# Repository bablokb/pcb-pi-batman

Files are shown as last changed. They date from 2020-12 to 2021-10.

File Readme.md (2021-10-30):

A pcb to support the battery management of mobile Pi-projects
=============================================================

Overview
--------

Since the Pi still drains power after shutdown, it is necessary
for battery-based projects to turn of the supply. This project uses
a very simple design to implement this.

One requisite is a DCDC-converter with an enable pin. As an alternative,
you can use a mosfet to switch power.

This repository contains two pcbs: the so called
_"minimal pcb"_ is nothing more than a flip-flop (SN74HC(T)74) with some
connectors for the converter and the Pi. The second pcb is a pHat designed
for a Pi-Zero.

Schematic Min-PCB
-----------------

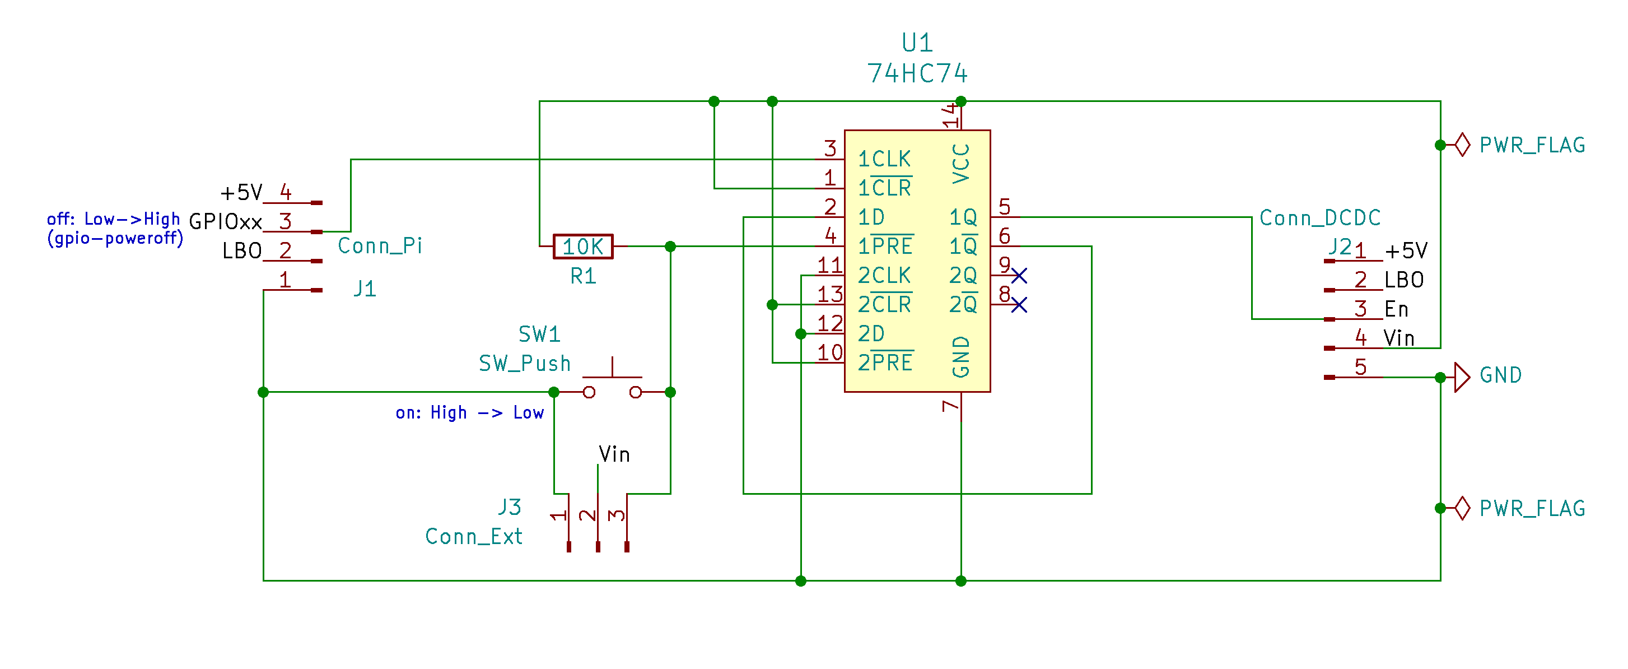
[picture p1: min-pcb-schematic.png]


The flip-flop drives the enable pin of the converter (pin 1Q). A button
(and/or RTC or sensor) pulls the reset pin (/1PRE) low to turn on power. A
GPIO from the Pi is connected to the clock-pin (pin 1CLK). The Pi will
pull this pin high on shutdown (see below). This will change the state
of the flip-flop: 1Q will take the value of 1D, which in turn is
connected to the inverted value /1Q (i.e. 1Q will switch to the current
value of /1Q).

The additional pin labelled _"LBO"_ is optional. Converters with a battery
monitoring can output a signal (_"low battery out"_) and if this is
connected to the Pi a program can react e.g. with an emergency
shutdown or an alarm if LBO is set.

Min-Pcb
-------

This is a very small pcb, useful if your project design needs it near
the battery pack:

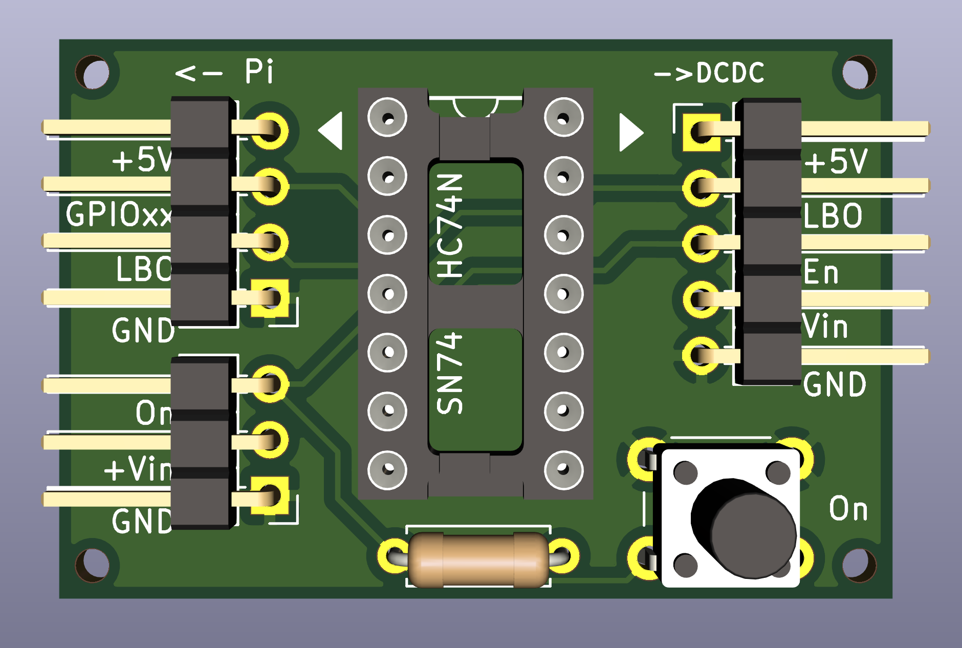
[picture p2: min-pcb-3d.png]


The layout is simple and the complete kicad-project is available in the
directory `min-pcb`.

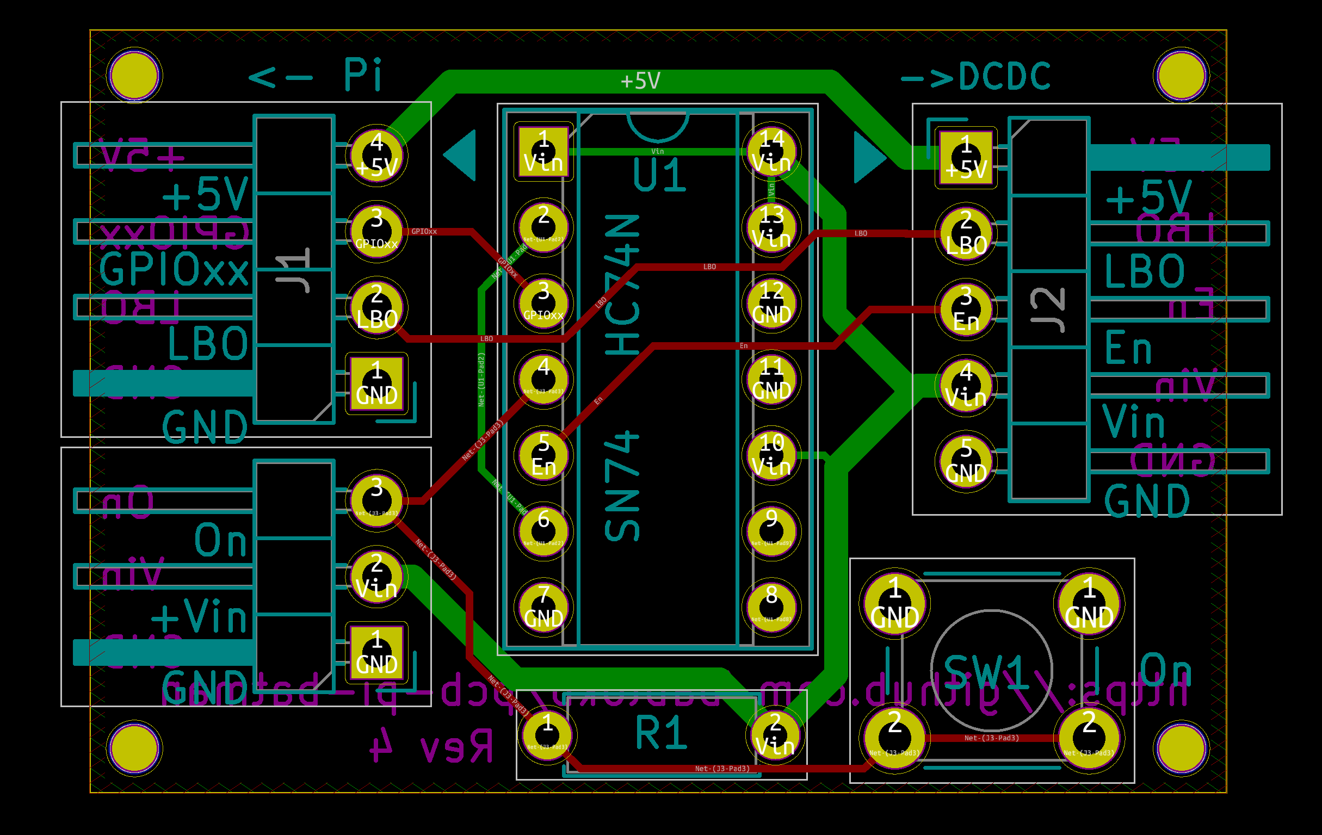
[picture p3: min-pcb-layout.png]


Schematic pHat-Pcb
------------------

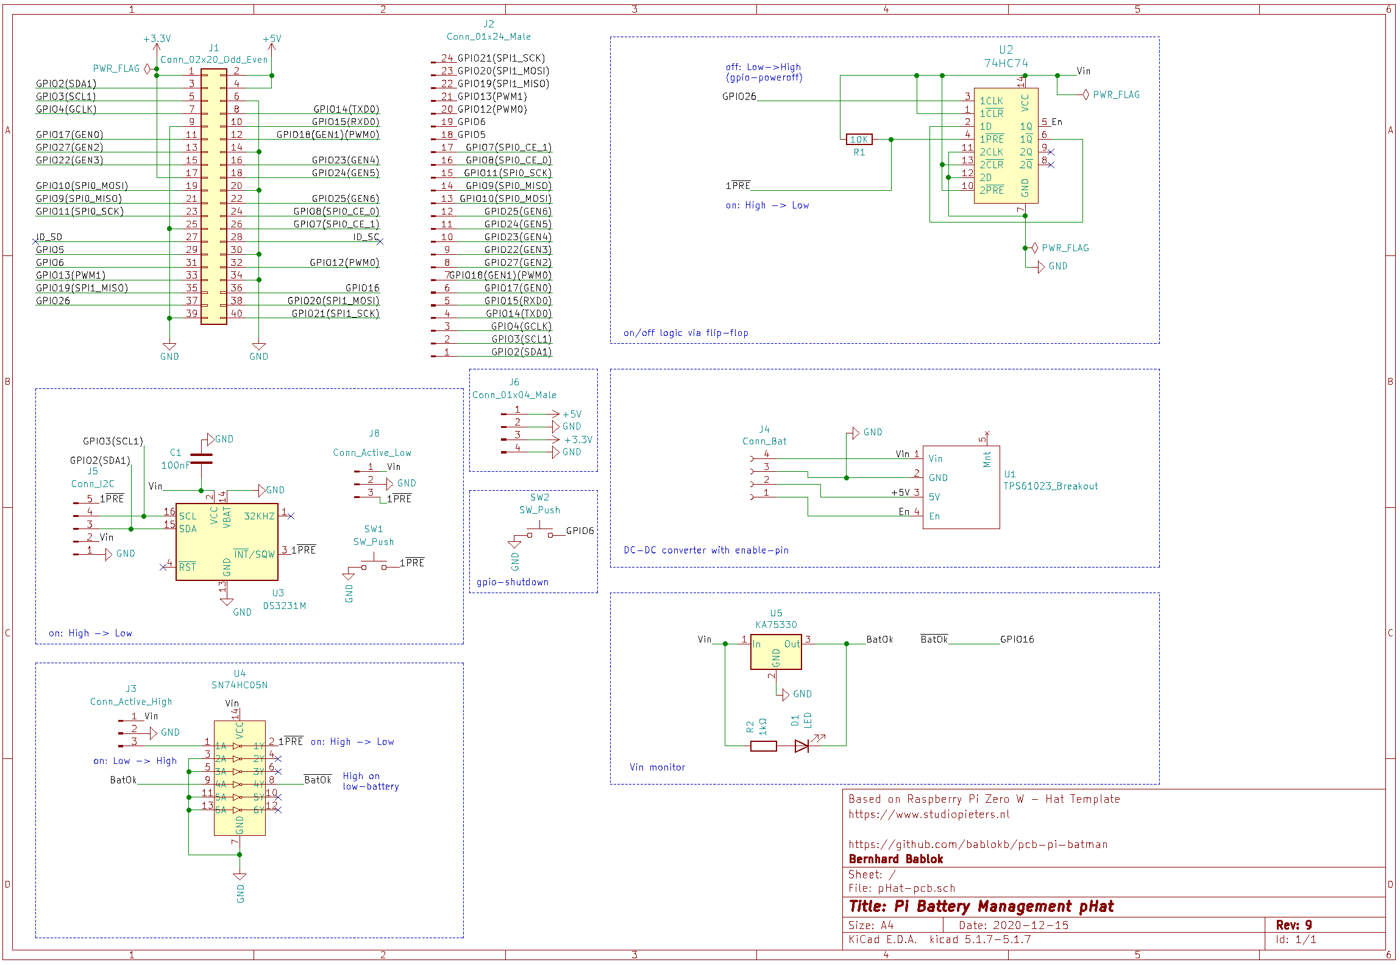
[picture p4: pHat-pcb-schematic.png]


This circuit is more sophisticated. The basis is the same, but it adds an
RTC (DS3231) for time-based boots and an inverter, mainly for turning on
power with a low-high transition. Also, the pcb has space for a
TPS61023 breakout (DC-DC converter) and for a KA75330 voltage-supervisor IC.

If you populate a LED+resistor, it will light up once the input
voltage drops below something like 3.15-3.45V (range of KA75330 according
to the datasheet). But in fact it might be a better idea not to
populate these two components: if voltage is low you don't want to
waste the rest of the battery for lighting up a LED?! For this reason
the inverted signal is also connected to GPIO16, so the Pi can react
and maybe shutdown or send a low-battery mail.

Another optional component is a second switch, directly attached to the Pi
(GPIO6). See the configuration section below to see how you can
shutdown the Pi with this button (you can use it for other purposes as well).

pHat-Pcb
--------

The format of the pcb is a zero-sized hat without beeing a formal pHat:

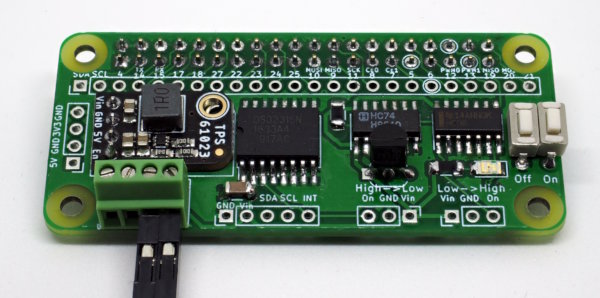
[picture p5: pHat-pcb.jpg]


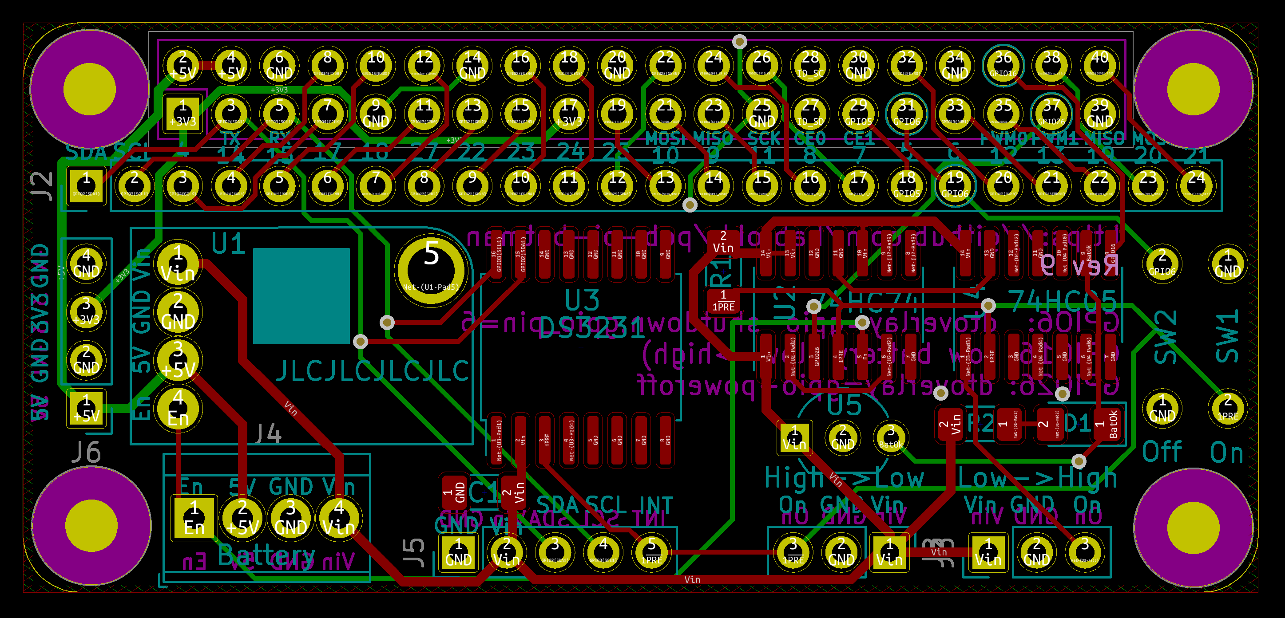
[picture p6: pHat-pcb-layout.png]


The hat breaks out most of the GPIOs, except for GPIO6, GPIO16 and GPIO26.

The following components are optional:

  - TPS61023 DC-DC converter
    (you can externaly connect battery, 5V and enable pin instead)
  - DS3131 RTC
  - KA75330 + LED + resistor
  - all connectors

Pi Configuration Min-Pcb
------------------------

The Pi has to signal shutdown to the pcb. Simply add the following
line to your `/boot/config.txt`:

    dtoverlay=gpio-poweroff,gpiopin=26

Note that the default is GPIO26 (physical pin 37). You cannot
just use any pin, since on power-on the pin has to be pulled low
until the gpio-poweroff driver takes over.

Pi Configuration pHat-Pcb
-------------------------

This pcb has multiple connections to the Pi. Add following lines to
your `/boot/config.txt`:

    dtoverlay=i2c-rtc,ds3231,wakup-source
    dtoverlay=gpio-shutdown,gpio_pin=6
    dtoverlay=gpio-poweroff,gpiopin=26
    dtoverlay=gpio-key,gpio=16,active_low=0,gpio_pull=off,label=lbo,keycode=xx

The first line is to activate the rtc, the last line triggers the
configured key on a battery low signal. This is just an example, there
are other ways to monitor GPIO16 for a low-high transition.

For the rtc you need an additional file `/etc/udev/rules.d/85-hwclock.rules`
with the content:

    KERNEL=="rtc0", RUN+="/sbin/hwclock -s -u -f $root/$name"

License
-------

Shield: [![CC BY-SA 4.0][cc-by-sa-shield]][cc-by-sa]

This work is licensed under a
[Creative Commons Attribution-ShareAlike 4.0 International
License][cc-by-sa].

[][cc-by-sa]

[cc-by-sa]: http://creativecommons.org/licenses/by-sa/4.0/
[cc-by-sa-image]: https://licensebuttons.net/l/by-sa/4.0/88x31.png
[cc-by-sa-shield]:
https://img.shields.io/badge/License-CC%20BY--SA%204.0-lightgrey.svg

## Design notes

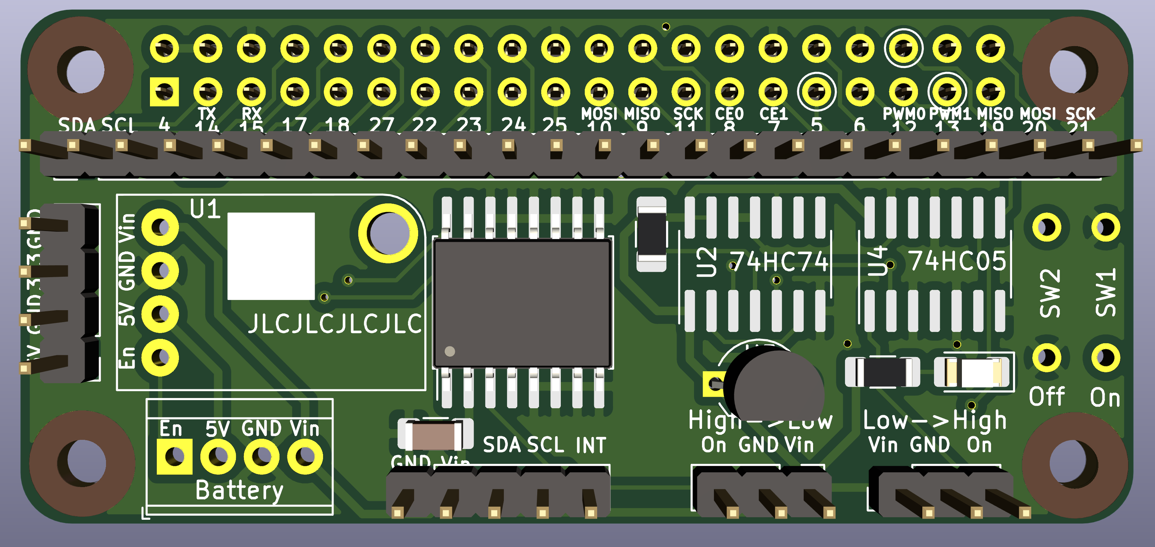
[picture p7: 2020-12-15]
pHat-pcb-3d.png

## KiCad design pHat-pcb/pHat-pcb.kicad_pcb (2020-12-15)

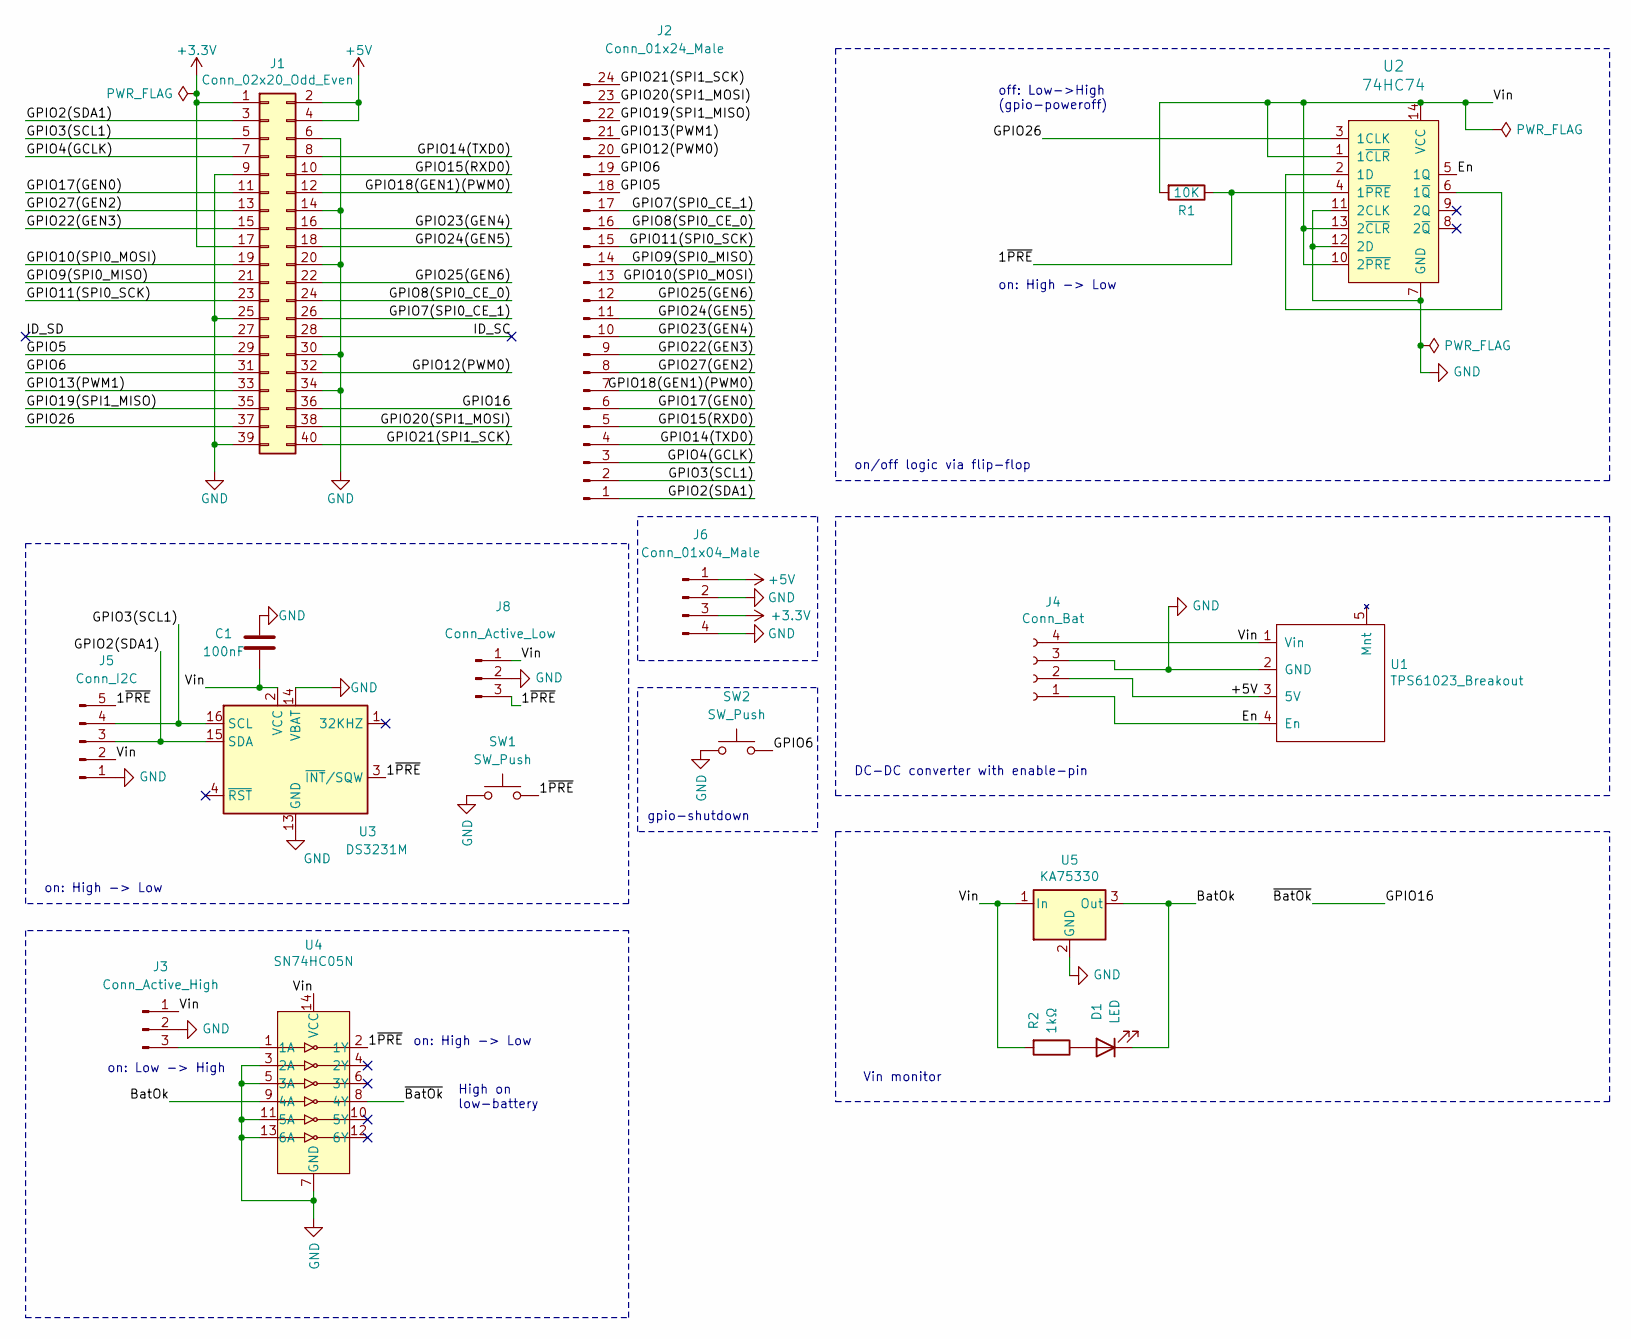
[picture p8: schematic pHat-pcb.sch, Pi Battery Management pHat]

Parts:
C1: 100nF; C_1206_3216Metric_Pad1.33x1.80mm_HandSolder
D1: LED; LED_1206_3216Metric_Pad1.42x1.75mm_HandSolder
J1: Conn_02x20_Odd_Even; PinSocket_2x20_P2.54mm_Vertical
J2: Conn_01x24_Male; PinHeader_1x24_P2.54mm_Vertical
J3: Conn_Active_High; PinHeader_1x03_P2.54mm_Vertical
J4: Conn_Bat; TerminalBlock_TE_282834-4_1x04_P2.54mm_Horizontal
J5: Conn_I2C; PinHeader_1x05_P2.54mm_Vertical
J6: Conn_01x04_Male; PinHeader_1x04_P2.54mm_Vertical
J8: Conn_Active_Low; PinHeader_1x03_P2.54mm_Vertical
R1: 10K; R_1206_3216Metric_Pad1.30x1.75mm_HandSolder
R2: 1kΩ; R_1206_3216Metric_Pad1.30x1.75mm_HandSolder
SW1, SW2: SW_Push; SW_PUSH_SLIM_1x4
U1: TPS61023_Breakout
U2: 74HC74; SO-14_3.9x8.65mm_P1.27mm_HandSolder; MPN SN74HC74N; Digi-Key_PN 296-1602-5-ND
U3: DS3231M; SOIC-16W_7.5x10.3mm_P1.27mm_HandSolder
U4: SN74HC05N; SO-14_3.9x8.65mm_P1.27mm_HandSolder
U5: KA75330; TO-92_Inline_Wide

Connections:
+3V3: J1.1, J1.17, J6.3
+5V: J1.2, J1.4, J4.2, J6.1, U1.3 (5V)
/1~PRE: J5.5, J8.3, R1.1, SW1.2, U2.4 (1~PRE), U3.3 (~INT~/SQW), U4.2 (1Y)
/BatOk: D1.1 (K), U4.9 (4A), U5.3 (Out)
/En: J4.1, U1.4 (En), U2.5 (1Q)
/GPIO2(SDA1): J1.3, J2.1, J5.3, U3.15 (SDA)
/GPIO3(SCL1): J1.5, J2.2, J5.4, U3.16 (SCL)
/GPIO4(GCLK): J1.7, J2.3
/GPIO5: J1.29, J2.18
/GPIO6: J1.31, J2.19, SW2.2
/GPIO7(SPI0_CE_1): J1.26, J2.17
/GPIO8(SPI0_CE_0): J1.24, J2.16
/GPIO9(SPI0_MISO): J1.21, J2.14
/GPIO10(SPI0_MOSI): J1.19, J2.13
/GPIO11(SPI0_SCK): J1.23, J2.15
/GPIO12(PWM0): J1.32, J2.20
/GPIO13(PWM1): J1.33, J2.21
/GPIO14(TXD0): J1.8, J2.4
/GPIO15(RXD0): J1.10, J2.5
/GPIO16: J1.36, U4.8 (4Y)
/GPIO17(GEN0): J1.11, J2.6
/GPIO18(GEN1)(PWM0): J1.12, J2.7
/GPIO19(SPI1_MISO): J1.35, J2.22
/GPIO20(SPI1_MOSI): J1.38, J2.23
/GPIO21(SPI1_SCK): J1.40, J2.24
/GPIO22(GEN3): J1.15, J2.9
/GPIO23(GEN4): J1.16, J2.10
/GPIO24(GEN5): J1.18, J2.11
/GPIO25(GEN6): J1.22, J2.12
/GPIO26: J1.37, U2.3 (1CLK)
/GPIO27(GEN2): J1.13, J2.8
/ID_SC: J1.28
/ID_SD: J1.27
/Vin: C1.2, J3.1, J4.4, J5.2, J8.1, R1.2, R2.2, U1.1 (Vin), U2.1 (1~CLR), U2.10 (2~PRE), U2.13 (2~CLR), U2.14 (VCC), U3.2 (VCC), U4.14 (VCC), U5.1 (In)
GND: C1.1, J1.6, J1.9, J1.14, J1.20, J1.25, J1.30, J1.34, J1.39, J3.2, J4.3, J5.1, J6.2, J6.4, J8.2, SW1.1, SW2.1, U1.2 (GND), U2.7 (GND), U2.11 (2CLK), U2.12 (2D), U3.5 (GND), U3.6 (GND), U3.7 (GND), U3.8 (GND), U3.9 (GND), U3.10 (GND), U3.11 (GND), U3.12 (GND), U3.13 (GND), U3.14 (VBAT), U4.3 (2A), U4.5 (3A), U4.7 (GND), U4.11 (5A), U4.13 (6A), U5.2 (GND)
unnamed: D1.2 (A), R2.1
unnamed: J3.3, U4.1 (1A)
unnamed: U2.2 (1D), U2.6 (1~Q)

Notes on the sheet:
off: Low->High (gpio-poweroff)
on: High -> Low
on: Low -> High
on/off logic via flip-flop
DC-DC converter with enable-pin
High on low-battery
Vin monitor
gpio-shutdown

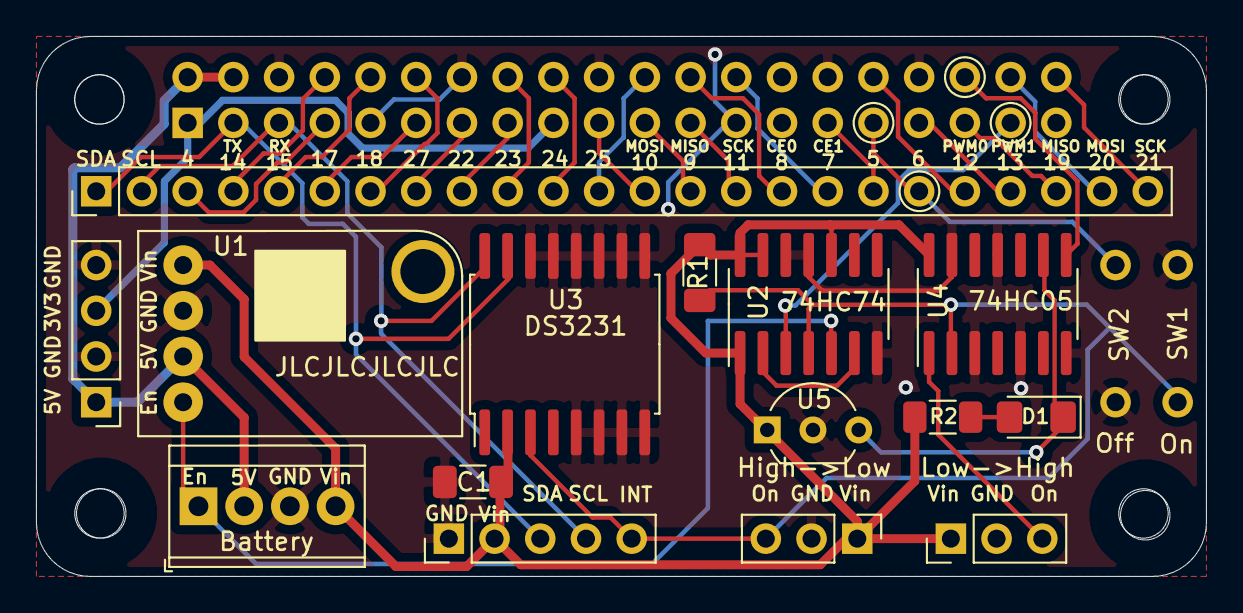
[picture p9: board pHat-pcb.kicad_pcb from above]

Board: 2 copper layers, 65.0 x 30.0 mm, 18 parts (1 on the bottom side), 36 nets.

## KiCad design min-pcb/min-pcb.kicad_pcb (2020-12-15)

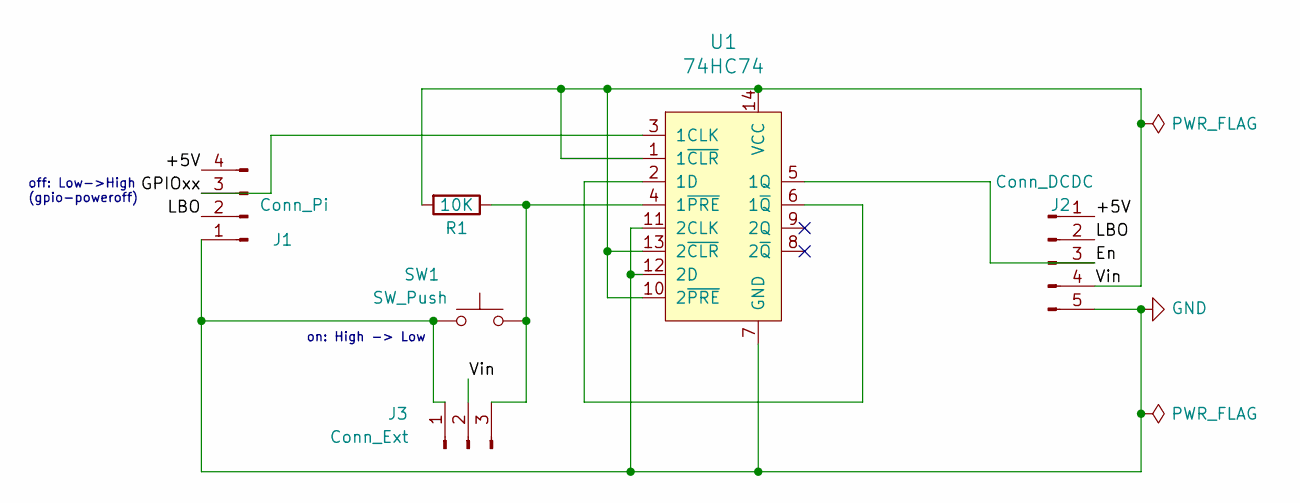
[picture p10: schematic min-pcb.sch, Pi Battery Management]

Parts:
J1: Conn_Pi; PinHeader_1x04_P2.54mm_Horizontal
J2: Conn_DCDC; PinHeader_1x05_P2.54mm_Horizontal
J3: Conn_Ext; PinHeader_1x03_P2.54mm_Horizontal
R1: 10K; R_Axial_DIN0207_L6.3mm_D2.5mm_P7.62mm_Horizontal
SW1: SW_Push; SW_PUSH_6mm_H9.5mm
U1: 74HC74; DIP-14_W7.62mm_Socket; MPN SN74HC74N; Digi-Key_PN 296-1602-5-ND

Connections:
/+5V: J1.4, J2.1
/En: J2.3, U1.5 (1Q)
/GPIOxx: J1.3, U1.3 (1CLK)
/LBO: J1.2, J2.2
/Vin: J2.4, J3.2, R1.2, U1.1 (1~CLR), U1.10 (2~PRE), U1.13 (2~CLR), U1.14 (VCC)
GND: J1.1, J2.5, J3.1, SW1.1, U1.7 (GND), U1.11 (2CLK), U1.12 (2D)
unnamed: J3.3, R1.1, SW1.2, U1.4 (1~PRE)
unnamed: U1.2 (1D), U1.6 (1~Q)

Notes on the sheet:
off: Low->High (gpio-poweroff)
on: High -> Low

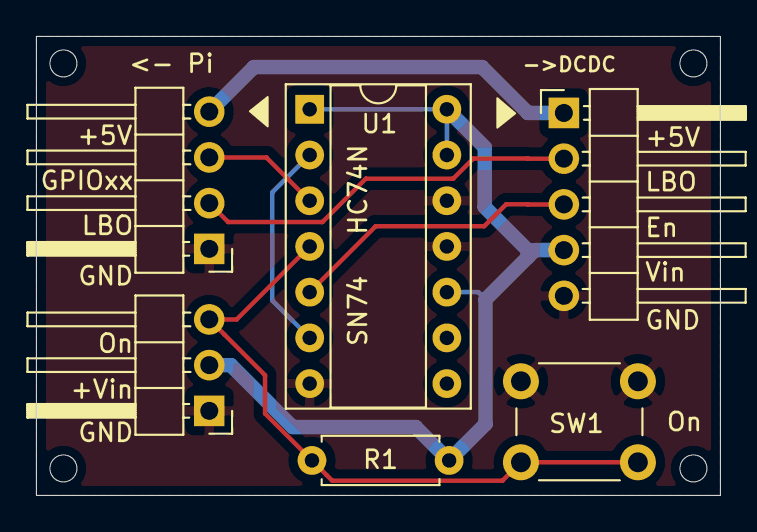
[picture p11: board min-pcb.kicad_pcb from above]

Board: 2 copper layers, 38.0 x 25.5 mm, 6 parts (0 on the bottom side), 8 nets.

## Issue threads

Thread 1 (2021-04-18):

Schematic question

seamusdemora, 2021-04-18:
*Note: It was confusing me trying to keep the [pi-wake-on-rtc questions](https://github.com/bablokb/pi-wake-on-rtc/issues/2) separated from the references to this repo - I'll try to keep my questions organized under the proper repo going forward.*
---

1. In the schematic area showing the DS3231, there is no pullup resistor shown on the `1PRE` line (pin 3, DS3231).
2. The `1PRE` signal leaves this bounding box on `J8, Conn_Active_Low`.
3. The `1PRE` signal *seems* to reappear in the bounding box for the 74HC05 inverter on `J3, Conn_Active_High`, emerging from the inverter output with the same name & notation `ON: High-> Low`

Is this all as you intended? The data sheet says a pullup is required on the `INT/SQW` output, and seems to me the transition on pin 2 of the inverter should be `Low -> High`.

Finally, I could find no description of the battery... did I miss that? I ask because the DC-DC converter * U5 suggest a 3.3 volt battery is powering the RPi - is that correct?

bablokb, 2021-04-18:
Hi,

1. the pullup is in the upper right box, R1
2. J8 is for external inputs that trigger on High-Low. This is optional, e.g. to add an external button.
3. J3 is also for external inputs, that trigger on Low->High. I use this for touch-sensor buttons.

The diagram (Kicad) uses the names to connect all components together, i.e. nothing "leaves" a box and reappears, it is just to prevent clutter. All /1PRE are connected together, you could draw lines instead. So /1PRE off the flip-flop has four inputs: the push-button SW1, the DS3231, the external input from J8 and the (inverted) external input from J3 (via the inverter).

Regarding the battery: I use 3.7V LiPos. For the "minimal" PCB, I successfully used Adafruit's PowerBoost modules. For the hat-pcb I just attach a standard 18650 industry-lipo because the TPS61023 converter is on the hat. In both cases, the Pi is powered by 5V after DC-DC conversion.

I hope this helps.

seamusdemora, 2021-05-16:
Another question:

Can you provide a brief explanation of what the `85-hwclock.rules` file does?

bablokb, 2021-05-17:
This is a rule for the udev-daemon. As soon as the kernel loads the rtc module and the rtc0 device pops up, the daemon executes the given command. You should read `man hwclock` for details, but the short story is: the commands sets the system-time from the time within the rtc (assuming the rtc keeps the time while the system is down).

I have read that this rule is no longer necessary but I noticed in my environments that this not valid.

seamusdemora, 2021-05-18:
> I have read that this rule is no longer necessary but I noticed in my environments that this not valid.

That's interesting... Like you, I have read that the RTC should typically "just work" wrt keeping system clock up-to-date. `man hwclock` sheds more light on the inter-relationships between the RTC, `timesyncd` and the "system time".  I have read it, but I was looking for something different.

I'm using an RPi 3B+ for my RTC developments. Currently it is also connected to my WiFi network, but when deployed, it must work with or without WiFi. I have largely assumed this will "just work", but now your experience makes me wonder. Furthering my confusion: it's not yet clear to me how the system arbitrates **which** of these two time sources is used, and I have learned that the DS3231 chip used in my RTC module is a ***counterfeit*** - so its' accuracy is in question.

Given this new uncertainty, I'm strongly motivated to test this. I'd appreciate your input on a test procedure: I'm thinking the best way to test this is as follows:  turn off the `timesyncd` service:

```
$ sudo systemctl stop systemd-timesyncd.service
```

And then monitor the system time "by observation" against a known-accurate clock. Any better ideas would be much appreciated.

bablokb, 2021-05-18:
Usually a system will only update the system-clock once at boot time from the rtc and then at regular intervals from ntp time-sources. So for normal systems the (early) rtc-update is only useful for good timestamps in the boot logs. The system also detects if it's own system-clock is not exact and tries to take this into account during times without ntp-access.

I would not worry too much about a counterfeit model if you don't get near the specification-limits (e.g. low temperature or supply voltage). For a test, you should define the error you can live with (e.g. 1s per day) and then use your test-procedure and wait a few days (to keep your "sample" error low). And if you really have a long running system without internet access, you could also correct the time yourself once you know how far it is off.

If you really want to automate this, you could use something like http://worldtimeapi.org/api/timezone/ which will return the time without updating your clock, but of course you have the runtime of the request as well so this depends on the latency of your connection and of this service and how far your clock is off.

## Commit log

2020-09-22 optimzed traces
    [min-pcb.kicad_pcb]
2020-09-22 rearranged pins on connectors
    [min-pcb.kicad_pcb, min-pcb.sch]
2020-09-23 Rev2: added power to external connector, added mounting-holes
    [min-pcb.kicad_pcb, min-pcb.sch]
2020-09-23 plot-options for gerber-export
    [min-pcb.kicad_pcb]
2020-09-24 minor adjustment of connector positions to have some space for terminal-blocks
    [min-pcb.kicad_pcb]
2020-09-26 added textfield for JLC production-number
    [min-pcb.kicad_pcb]
2020-10-06 Rev 1: layout complete
    [pHat-pcb.kicad_pcb, pHat-pcb.sch]
2020-10-07 bugfix: labels +5V/GPIOxx were swapped on J1 (Pi-connector)
    [min-pcb.kicad_pcb]
2020-10-07 additional labels on the bottom
    [min-pcb.kicad_pcb]
2020-10-12 replaced 74HCT74 with 74HC74
    [min-pcb.kicad_pcb, min-pcb.sch]
2020-10-12 bugfix: replace 74HCT74 with 74HC74
    [pHat-pcb.kicad_pcb, pHat-pcb.sch]
2020-10-17 added capacitor to DS3231
    [pHat-pcb.sch]
2020-10-17 removed external LBO connector
    [pHat-pcb.sch]
2020-10-17 Rev2: with DS3231 cap and no LBO-connector
    [pHat-pcb.kicad_pcb]
2020-10-21 Rev3: added power-control IC and LED
    [pHat-pcb.kicad_pcb, pHat-pcb.sch]
2020-10-21 Rev4: added interrupt-pin for external I2C-connector
    [pHat-pcb.kicad_pcb, pHat-pcb.sch]
2020-10-23 replaced 74HC03 (nand) with 74HC05 (inverter)
    [pHat-pcb.sch]
2020-10-23 Rev5: drive LED from GPIO06
    [pHat-pcb.kicad_pcb, pHat-pcb.sch]
2020-10-27 Rev6: add connector for 5V, 3V3 and GND
    [pHat-pcb.kicad_pcb, pHat-pcb.sch]
2020-10-28 Rev7: added shutdown-button
    [pHat-pcb.kicad_pcb, pHat-pcb.sch]
2020-10-30 Rev8: add 5V to external battery connector / fixed KA75330 pin-order / updated labels
    [pHat-pcb.kicad_pcb, pHat-pcb.sch]
2020-12-15 bugfix: prevent 2nd flip-flop from floating
    [min-pcb.kicad_pcb, min-pcb.sch, pHat-pcb.kicad_pcb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]
